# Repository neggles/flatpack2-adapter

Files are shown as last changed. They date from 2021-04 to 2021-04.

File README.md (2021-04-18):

# EltekFlatpack2


This is my take on the Eltek Flatpack2 HE AC PSU adapter board (may also work with the DC-DC units); it's got a few nice features I like, like a plethora of connectivity options.

I've probably made some really bad design choices here, please don't judge me.

### *Update:* I've had a ludicrous number of these made, and they work great! 2oz copper & ENIG plated:

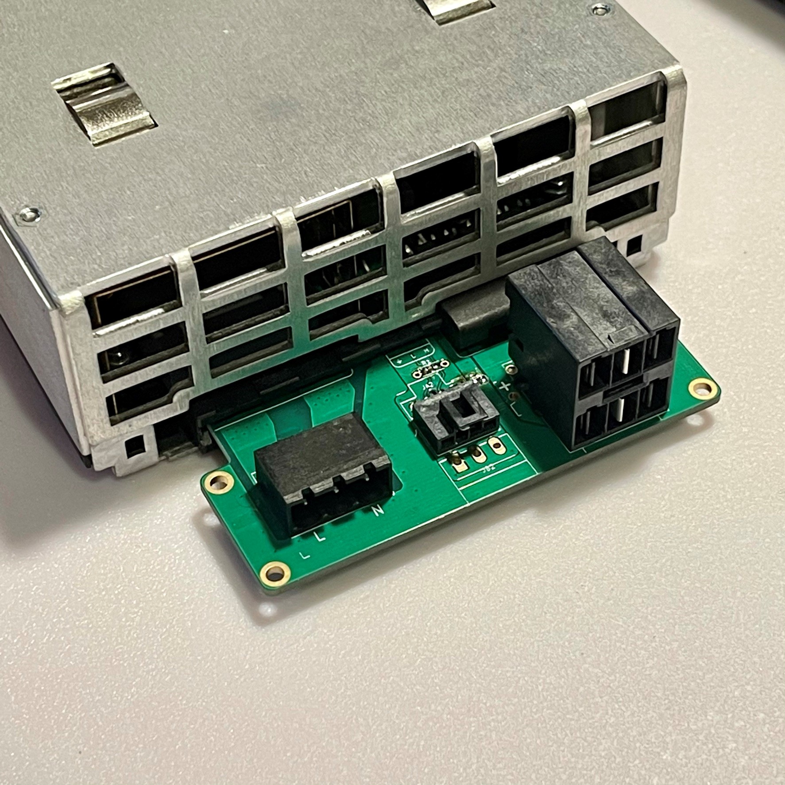
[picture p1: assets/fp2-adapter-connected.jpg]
Photo of finished board


### Render:

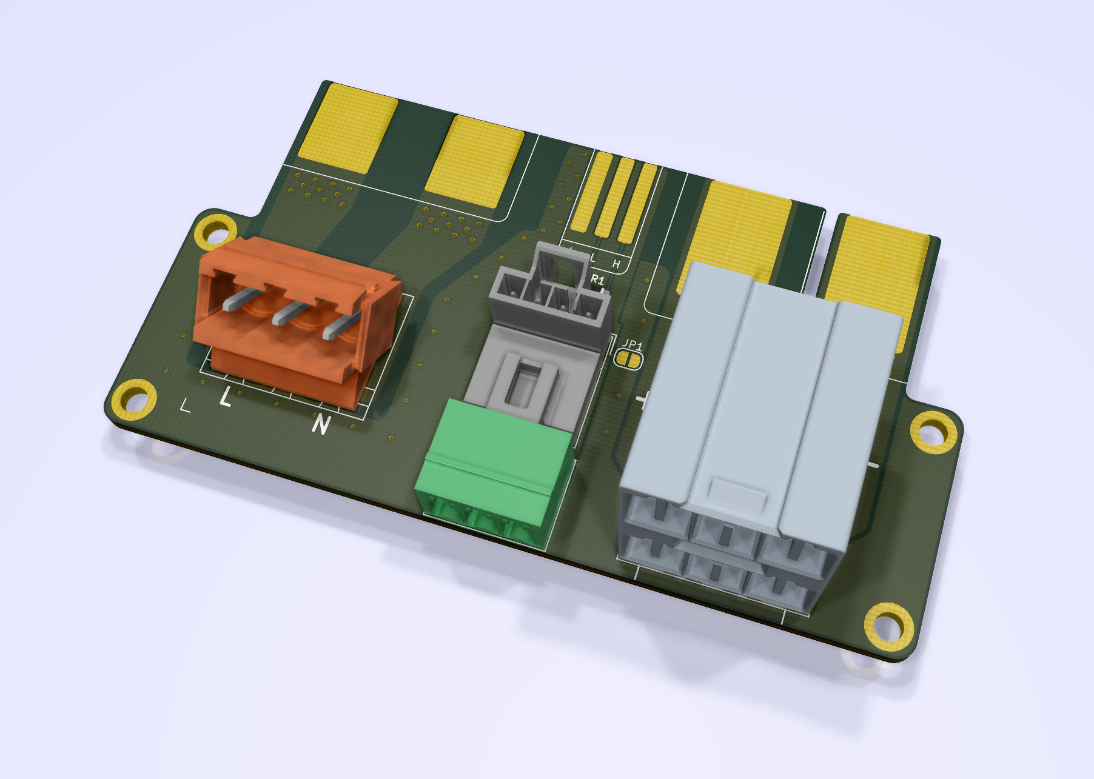
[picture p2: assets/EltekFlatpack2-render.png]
KiCad raytraced board render


## Features
I probably went a little bit overboard with connector options, but I wanted it to be flexible.

JP1 is a solder jumper that connects VOUT+ to J2 pin 1.
R1 is an optional 120R CANBUS termination resistor.

### AC Input footprints:
  - Standard 5.08mm-pitch pluggable terminal block of various kinds (5.0mm ones with small-ish pins should be able to squish into this as well)
  - WAGO 256-series (and similar) push-button actuated adjustable-pitch terminal blocks

### Controller CANBUS footprints:
- 4-pin 0.1" footprint with pinout VOUT+ CANH CANL GNDD.
  - 4P vertical Molex Nano-Fit [series 106309-1x04](https://www.molex.com/molex/search/deepSearch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)
  - 4P horizontal Molex Nano-Fit [105313-1x04](https://www.molex.com/molex/search/deepSearch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)
  - 3-pin vertical Molex Nano-Fit [106309-1x03](https://www.molex.com/molex/search/deepSearch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) keys into footprint pins 2-4. No controller power, like the secondary footprint.
- 3-pin 3.5mm footprint with pinout CANH CANL GNDD (no controller power)
  - Regular horizontal or vertical 3.5mm-pitch pluggable terminal block fits here.

### DC output footprints:
- TE Connectivity ELCON Mini 3P RA solder-in, [P/N 2204529-1](https://www.te.com/usa-en/product-2204529-1.html)
- TE Connectivity ELCON Mini 6P RA solder-in, [P/N 2204535-1](https://www.te.com/usa-en/product-2204535-1.html)
  - These will both take [P/N 2204534-1](https://www.te.com/usa-en/product-2204534-1.html) or [P/N 2204534-2](https://www.te.com/usa-en/product-2204534-2.html) plugs. Two fit into the 6-pin connector at the same time.
  - Contacts are TE's 5.8/6.3mm Standard Power Timer series, like [P/N 927837-5](https://www.te.com/usa-en/product-927837-5.html) and are rated for 35A per 3-pin set
- Amass XT60-PW solderable PCB-mount XT60 connector, commonly used for drone/RC shenanigans.
  - Rated at 30-60A depending on who you ask.
- The XT60-PW footprint also contains a 5.08mm terminal block pinout, and exposed pads for direct soldering.

## Repository Structure
- `EltekFlatpack2` contains the KiCad project
- `EltekFlatpack2/EltekFlatpack2.pretty` contains board-specific footprints
- `EltekFlatpack2/shapes3D` contains board-specific STEP models (and a few extra)

## Building
Simply call `make` in the top-top level directory. The `build` directory will then contain:

- the main board
- A panelized version of said board
- zipped gerbers for the boards you can directly use for manufacturing

### Credit where it's due:

Makefile uses [Jan Mrázek](https://github.com/yaqwsx)'s [KiKit](https://github.com/yaqwsx/KiKit), which I cannot recommend enough, and therefore has to be available on your system.

Jan's [jlcparts](https://yaqwsx.github.io/jlcparts/) app was also extremely useful in narrowing down part choices based on what JLCPCB have available.

### License
<br /><span xmlns:dct="http://purl.org/dc/terms/" property="dct:title">Flatpack2 Adapter</span> by <a xmlns:cc="http://creativecommons.org/ns#" href="https://github.com/neg2led" property="cc:attributionName" rel="cc:attributionURL">neg2led</a> is licensed under a <a rel="license" href="http://creativecommons.org/licenses/by-sa/4.0/">Creative Commons Attribution-ShareAlike 4.0 International License</a>.

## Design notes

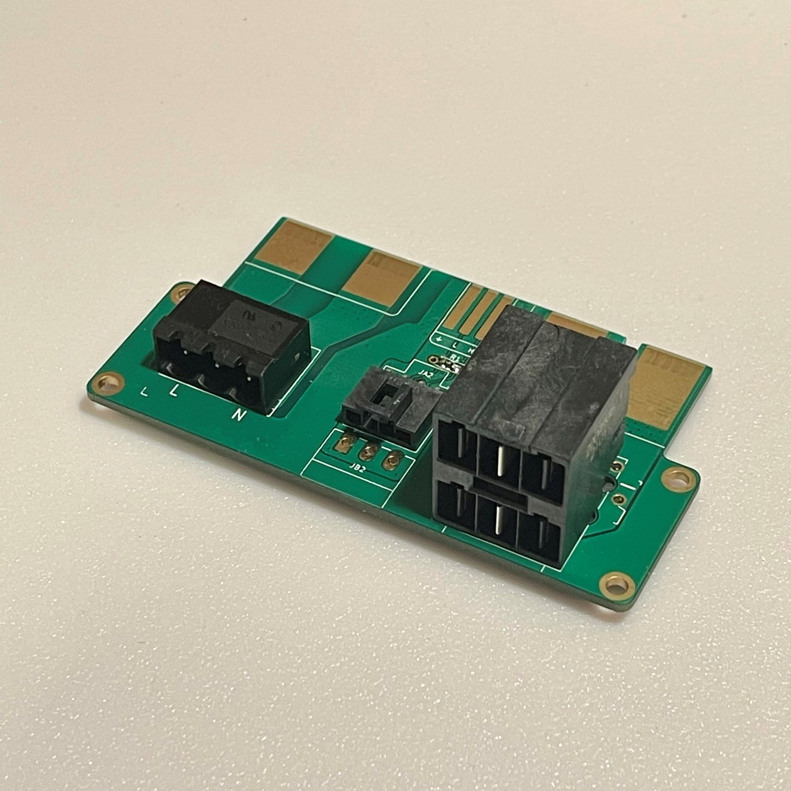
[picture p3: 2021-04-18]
assets/fp2-adapter.jpg

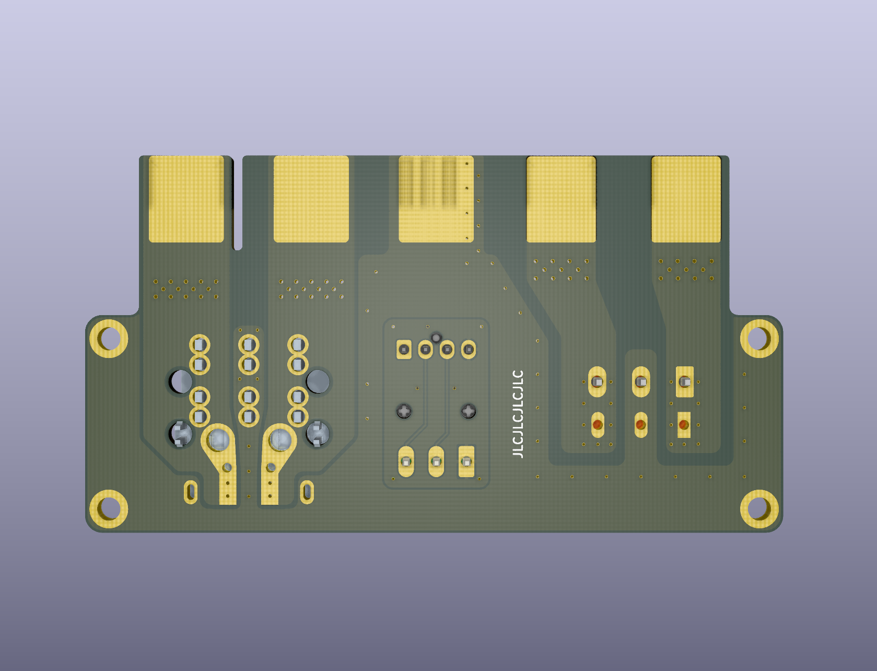
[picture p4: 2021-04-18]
assets/EltekFlatpack2-render-bottom.png

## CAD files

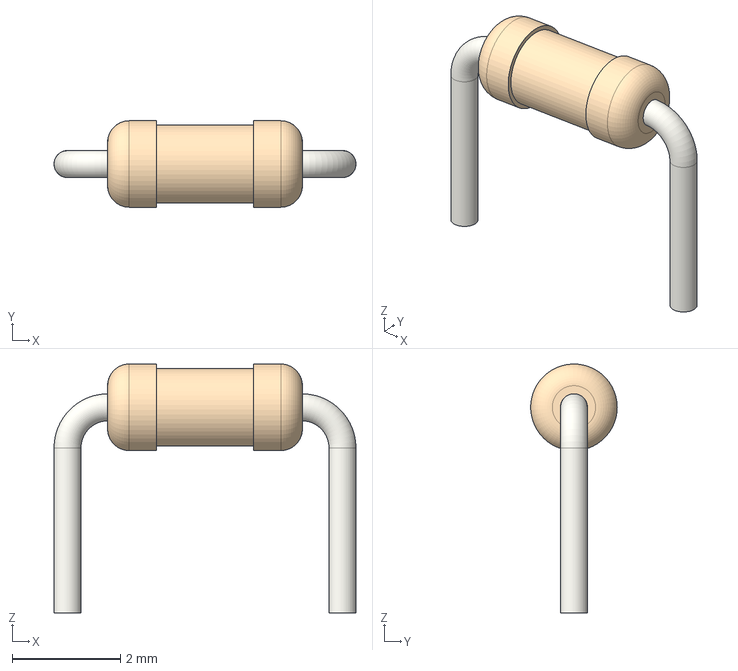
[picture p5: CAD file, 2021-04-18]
EltekFlatpack2/shapes3D/R_Axial_DIN0204_L3.6mm_D1.6mm_P5.08mm_Horizontal.step
5.58 x 1.60 x 4.60 mm

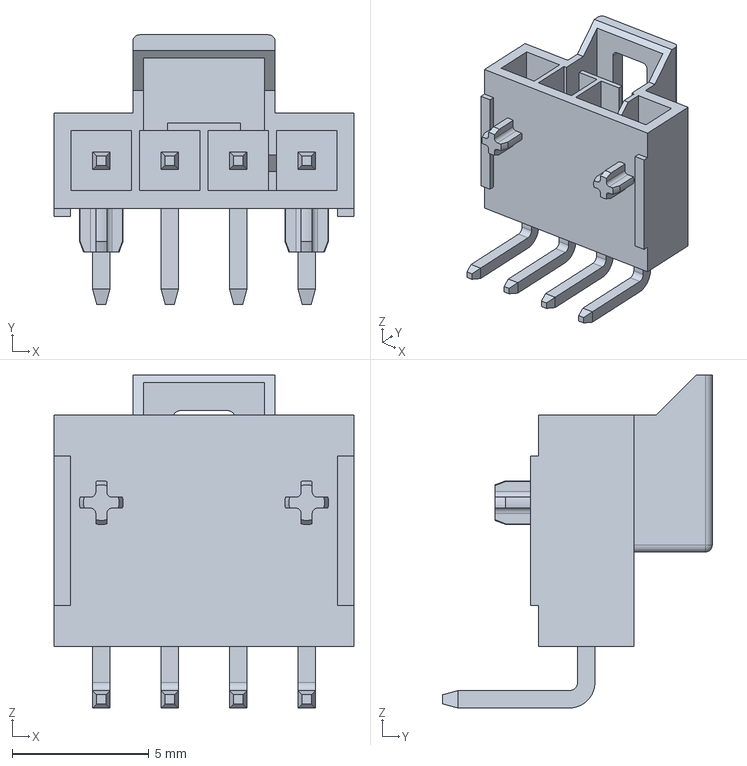
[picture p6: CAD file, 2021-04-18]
EltekFlatpack2/shapes3D/Molex_Nano-Fit_105313-xx04_1x04_P2.50mm_Horizontal.step
10.9 x 9.84 x 12.2 mm

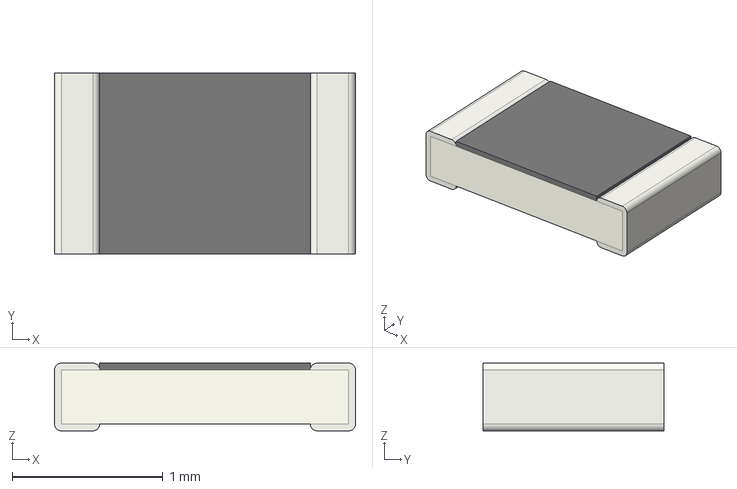
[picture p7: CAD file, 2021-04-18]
EltekFlatpack2/shapes3D/R_0805_2012Metric.step
2.00 x 1.20 x 0.45 mm

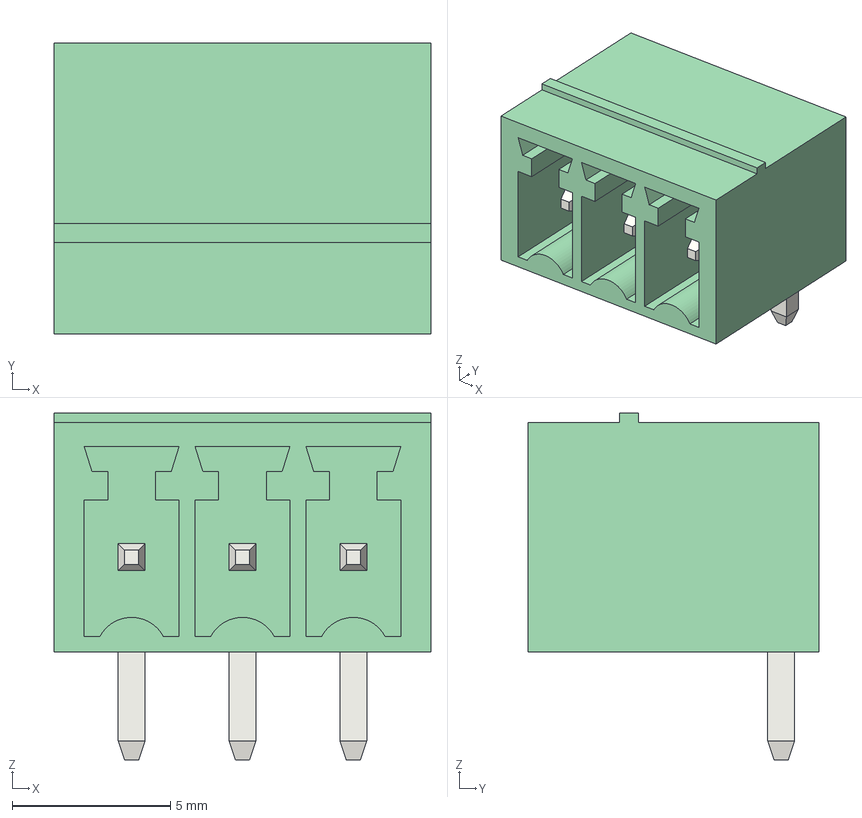
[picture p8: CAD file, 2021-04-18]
EltekFlatpack2/shapes3D/PhoenixContact_MC_1,5_3-G-3.5_1x03_P3.50mm_Horizontal.step
11.9 x 9.20 x 10.9 mm

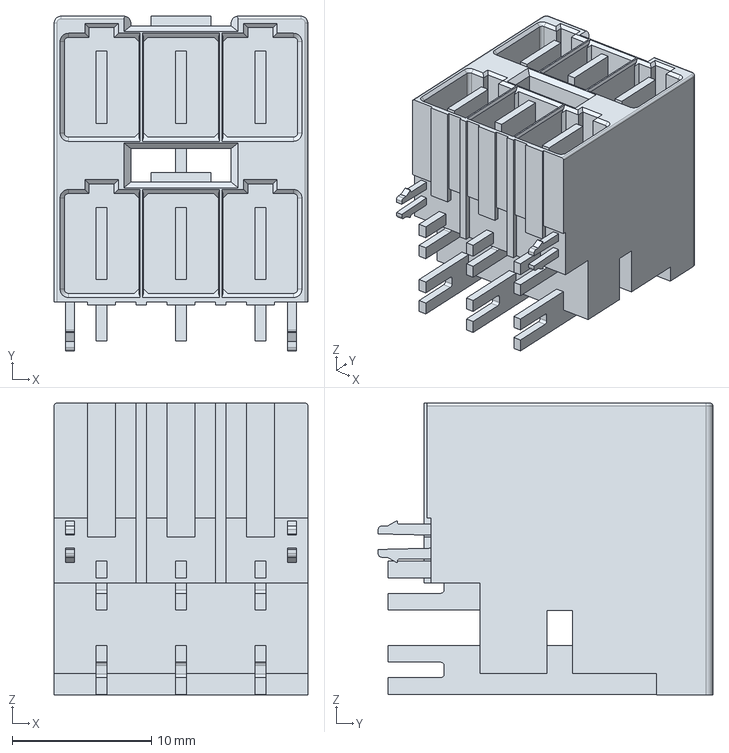
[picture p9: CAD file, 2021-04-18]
EltekFlatpack2/shapes3D/TE_2204535-1.stp
18.2 x 24.0 x 20.9 mm

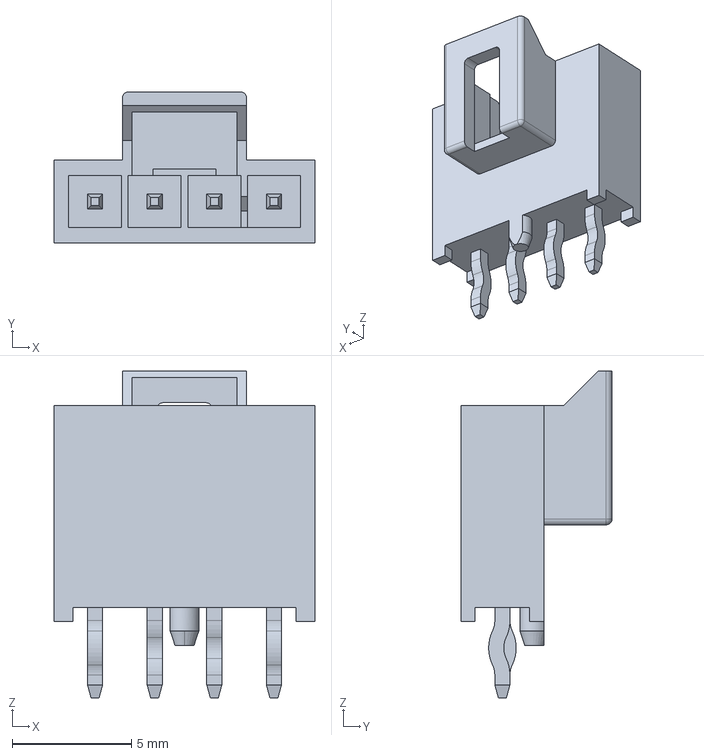
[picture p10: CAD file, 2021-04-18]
EltekFlatpack2/shapes3D/Molex_Nano-Fit_105309-xx04_1x04_P2.50mm_Vertical.step
10.9 x 6.34 x 13.7 mm

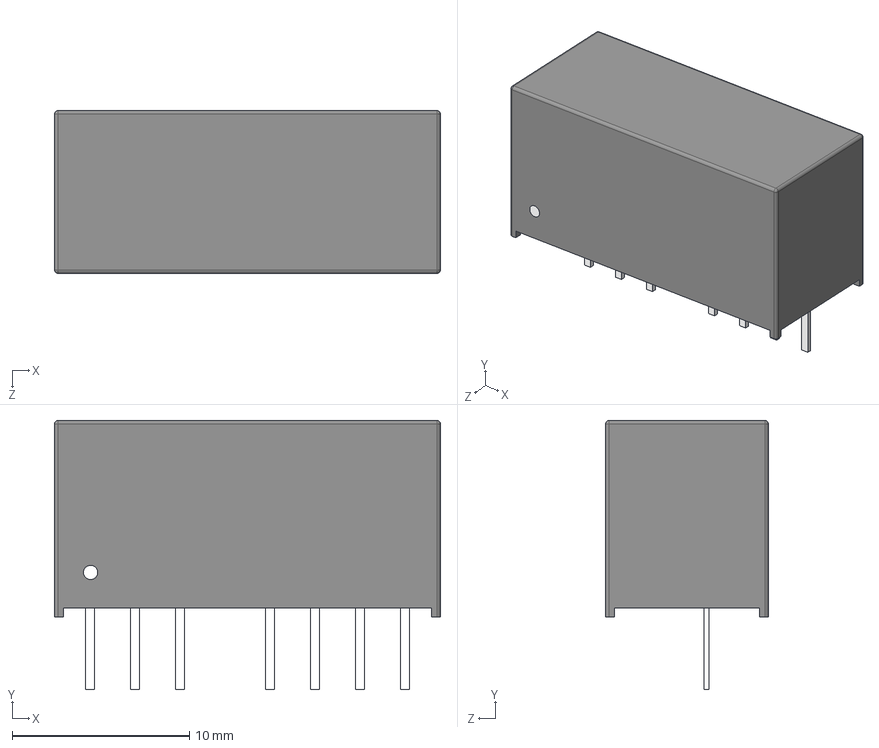
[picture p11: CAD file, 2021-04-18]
EltekFlatpack2/shapes3D/SPBW06F-12.step
21.8 x 15.2 x 9.20 mm

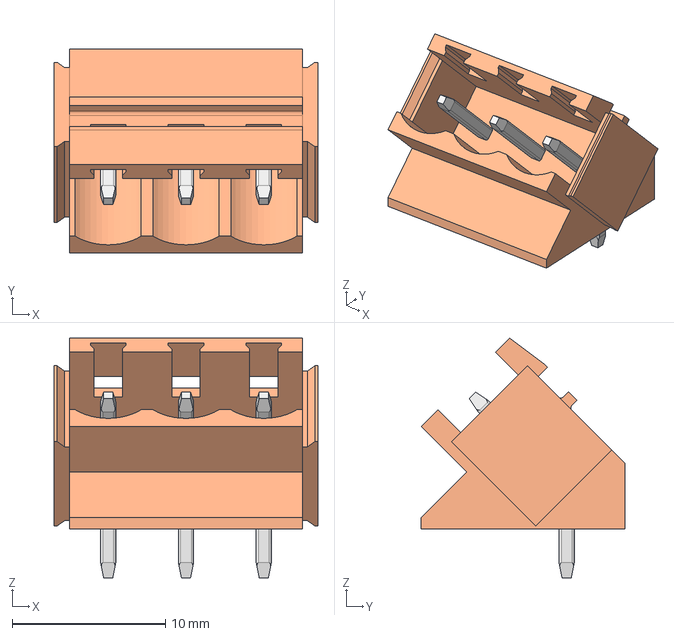
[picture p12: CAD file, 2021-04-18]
EltekFlatpack2/shapes3D/1605540000.stp
17.2 x 13.3 x 15.7 mm

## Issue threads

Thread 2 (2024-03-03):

CANbus to GND

joedupa, 2024-03-03:
Not really an issue, but how do you wire the CANbus ground connection on the board? Thanks

neggles, 2024-03-09:
Not entirely sure what you mean? The 4-pin connector in the middle has GND, CANH, CANL, and +V, and the 3-pin terminal block alternate has GND, CANH, and CANL

The four small pins on the PSU edge connector near the middle are specifically for this - one of them is a CAN GND reference pin 😄

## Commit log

2021-04-18 added dimensions
    [EltekFlatpack2.kicad_pcb]
2021-04-18 fix makefile/panel/footprint (now has 1mm mill hole and straight edges!)
    [EltekFlatpack2.kicad_pcb]
2021-04-18 add THT termination resistor option
    [EltekFlatpack2.kicad_pcb, EltekFlatpack2.sch]
2021-04-18 add keystone tab option
    [EltekFlatpack2.kicad_pcb, EltekFlatpack2.sch, R_Axial_DIN0204_L3.6mm_D1.6mm_P5.08mm_Horizontal.step]

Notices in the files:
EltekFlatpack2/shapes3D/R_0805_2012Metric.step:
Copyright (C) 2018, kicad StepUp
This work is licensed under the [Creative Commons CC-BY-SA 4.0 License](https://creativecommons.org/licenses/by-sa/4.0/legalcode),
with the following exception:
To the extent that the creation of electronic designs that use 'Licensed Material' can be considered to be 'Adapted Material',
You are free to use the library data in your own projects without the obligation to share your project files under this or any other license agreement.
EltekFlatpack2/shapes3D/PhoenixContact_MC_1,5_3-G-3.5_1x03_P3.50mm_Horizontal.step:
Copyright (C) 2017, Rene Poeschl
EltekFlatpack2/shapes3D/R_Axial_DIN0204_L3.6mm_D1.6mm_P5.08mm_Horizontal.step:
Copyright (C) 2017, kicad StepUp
